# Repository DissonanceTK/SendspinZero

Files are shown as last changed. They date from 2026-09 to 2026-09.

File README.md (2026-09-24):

# Minimalistic Sendspin Media Player for Home Assistant

NOTE: This is a DIY project, those that prefer Off-the-shelf devicea you can buy and use right away, there is a project for that here: https://github.com/RealDeco/sendspin-guition



A tiny [Sendspin](https://www.sendspin-audio.com) media player with **cover art display** and a **weather clock**, built around the **ESP32-S3 Zero**.

This project turns a small, inexpensive ESP32 board into a compact **audio receiver** for your amplifier capable of doing multi-room audio in sync, with a screen for album art, **song**, **artist**, and a weather clock when not playing, OR a Button to control with, or with nothing so you can hide it behind the tv/stereo.

Each version can be built with one of these options:

* Display
* No display
* Big button

That gives a total of **9 variants**:

Variants

---

<div align="center">

## Firmware Installers

<table>
  <tr>
    <th>Device / Configuration</th>
    <th>Installer</th>
  </tr>
  <tr>
    <td><strong>Sendspin Zero Button Analog</strong></td>
    <td></td>
  </tr>
  <tr>
    <td><strong>Sendspin Zero Button Digital</strong></td>
    <td></td>
  </tr>
  <tr>
    <td><strong>Sendspin Zero Display Analog</strong></td>
    <td></td>
  </tr>
  <tr>
    <td><strong>Sendspin Zero Display Digital</strong></td>
    <td></td>
  </tr>
  <tr>
    <td><strong>Sendspin Zero No Display Analog</strong></td>
    <td></td>
  </tr>
  <tr>
    <td><strong>Sendspin Zero No Display Digital</strong></td>
    <td></td>
  </tr>
</table>

<br>

<table>
  <tr>
    <td><strong>Sendspin Zero Control Analog</strong></td>
    <td></td>
  </tr>
  <tr>
    <td><strong>Sendspin Zero Control Digital</strong></td>
    <td></td>
  </tr>
  <tr>
    <td><strong>Sendspin Zero Display + Button Analog</strong></td>
    <td></td>
  </tr>
</table>

<br>

<table>
  <tr>
    <td><strong>SendspinZero Speaker</strong></td>
    <td></td>
  </tr>
  <tr>
    <td><strong>Sendspin Supermini Headphones</strong></td>
    <td></td>
  </tr>
</table>

</div>

---

## About the Project

This started as a fun experiment: I wanted to see if the **ESP32-S3 Zero** would work with Sendspin. Since it has **2 MB of PSRAM**, I figured it *might* be possible—and it turns out, it is.

Once that worked, I thought: instead of building yet another “Sendspin speaker”, why not make a **tiny receiver** for my amplifier?

So I:

* Replaced the **MAX98357** with a **PCM5102A DAC**
* Designed a custom case
* Added a display for **cover art** and a **weather clock**

…and this is the result 🙂

---

## Photos

<p align="center">
  
  
</p>

---

## Cost

All parts were sourced from AliExpress and added up to **just over $10** (last checked).

---

## Parts List

* **1 × ESP32-S3 Zero**
  [https://www.aliexpress.com/item/1005009890203011.html](https://www.aliexpress.com/item/1005009890203011.html)

  (be sure you select esp32-s3, not esp32-c3 which the page defaults to.)

* **1 × PCM5102A DAC**
  [https://www.aliexpress.com/item/1005008130629022.html](https://www.aliexpress.com/item/1005008130629022.html)

* **1 × 1.54" LCD screen**
  [https://www.aliexpress.com/item/1005008703777053.html](https://www.aliexpress.com/item/1005008703777053.html)

---

## Diagram & Pins Used

Wiring diagram

### ⚠️ Assembly Notes

* If you plan to mount everything inside the case, **do NOT solder header pins** to the DAC, ESP32, or display.
  → Solder wires directly to the boards instead, otherwise they won’t fit.

* If your display already has pins:
  → You may need to **bend two pins** slightly to make room for the audio jack.



---

## Pin Mapping

### ESP32-S3 → PCM5102A

| ESP32-S3 GPIO | PCM5102A Pin |
| --- | --- |
| GPIO4 | LRCK |
| GPIO5 | BCK |
| GPIO6 | DIN |

### ESP32-S3 → Display

| ESP32-S3 GPIO | Display Pin |
| --- | --- |
| GPIO7 | SCL |
| GPIO8 | SDA |
| GPIO9 | RST |
| GPIO10 | DC |
| GPIO11 | BL |

### Power (both modules)

* **GND**
* **3.3V**

# >>>> Important DAC Setup <<<< (or there will be no sound)

Make sure to:

* Solder the 4 control pads on the **back of the PCM5102A** (also shown below):
  * H1L -> L
  * H2L -> L
  * H3L -> H
  * H4L -> L
* Solder the bridge near **SCK on the front** (some boards come pre-soldered)



---

## Toslink (Optical Audio) Version

This version has **no display** and is the easiest build—**under $10** 🙂

(For display or button versions, pin usage is the same)

Toslink version

Your soundbar will love you for it 😉
3D files are in [`3D_Files`](3D_Files)

### Pin Mapping

### ESP32-S3 → Toslink Connector

| ESP32-S3 GPIO | TOSLINK |
| --- | --- |
| GPIO4 | VIN (DATA) |
| 3.3V | VCC |
| GND | GND |

Pins

### Parts

* Single: [https://www.aliexpress.com/item/1005011593001325.html](https://www.aliexpress.com/item/1005011593001325.html)
* 1–10 pcs: [https://www.aliexpress.com/item/1005008393864163.html](https://www.aliexpress.com/item/1005008393864163.html)
* Cables: [https://www.aliexpress.com/item/1005008202856228.html](https://www.aliexpress.com/item/1005008202856228.html)

- 1 × M2.6×10 self-tapping screw

⚠️ **Important:** Select **"Transmitting end" (A1)**

---

## Coax (Digital Audio) Version

Simplest version of all: **just two wires and a resistor**.

Coax version

3D files are in [`3D_Files`](3D_Files)

### Pin Mapping

### ESP32-S3 → RCA Connector

| ESP32-S3 GPIO | RCA |
| --- | --- |
| GPIO4 | VIN (DATA) |
| GND | GND |

### Parts

* 1 pcs. 332-470ohm resistor [https://www.aliexpress.com/item/1005005252979796.html](https://www.aliexpress.com/item/1005005252979796.html)

* RCA female: [https://www.aliexpress.com/item/1005010424983352.html](https://www.aliexpress.com/item/1005010424983352.html)
* Cables: [https://www.aliexpress.com/item/1005008202856228.html](https://www.aliexpress.com/item/1005008202856228.html)

---

## Button Version

Instead of a display, you can use a **large illuminated button**.

### Controls

* **Single click** → Play / pause
* **Double click** → Next track
* **Triple click** → Previous track
* **Hold** → Toggle Sendspin / Home Assistant control mode

In HA mode, clicks are exposed for automations.



3D files are in [`3D_Files`](3D_Files)

### Pin Mapping

| ESP32-S3 GPIO | Button |
| --- | --- |
| GPIO1 | 1 |
| GPIO2 | 3 |
| GPIO3 | 4 |
| GND | 2 + 5  |



### Part

**22mm Bicolor (RG) Black 3–6V**
[https://www.aliexpress.com/item/1005004920346156.html](https://www.aliexpress.com/item/1005004920346156.html)

---

## SendspinZero-Control (Knob + Button + Display)

This version uses a combo board with a **rotary encoder + button + display i found cheap on aliexpress**.



3D files are in [`3D_Files`](3D_Files)

### Additional Pins

(Same as display version + these)

| ESP32-S3 GPIO | Combo Board |
| --- | --- |
| GPIO12 | TRA |
| GPIO13 | TRB |
| GPIO43 (TX) | PSH |
| GPIO44 (RX) | KO |

(TX = GPIO43, RX=GPIO44 on the zero board)



### Part

ESP32-S3 Zero and PCM5102A as above +

[https://www.aliexpress.com/item/1005009900611104.html](https://www.aliexpress.com/item/1005009900611104.html)

---

## Display + Button Version



3D files are in [`3D_Files`](3D_Files)

### Pin Mapping

Same as SendspinZero-Display + SendspinZero-Button

### Parts

same components as the other versions (esp32-s3 + PCM5102A DAC + Button) +

* 1.9" screen: [https://www.aliexpress.com/item/1005007098895718.html](https://www.aliexpress.com/item/1005007098895718.html)

---

## Speaker amplifier version





NO 3D files made for this device.

This is the only device with amplifier onboard, it's mono so for stereo speakers you need a module for each speaker and have them playing as stereo in MA.

### Pin Mapping
(remove two pins from the spacer and solder the boards together)

| ESP32-S3 GPIO | MAX98357 |
| --- | --- |
| VCC (5V) | Vin |
| GND | GND |
| *not used* | SD |
| *not used* | GAIN |
| GPIO2 | DIN |
| GPIO3 | BCLK |
| GPIO4 | LRC |

GAIN pin can be connected to GND for 12db gain. (or with 100k resistor to GND for 15db gain)

### Parts

same esp32-s3 zero as the other versions +

* MAX98357: https://www.aliexpress.com/item/1005007003802663.html

---

## Supermini Headphone amplifier version (make corded headphones wireless)



3D files are in [`3D_Files`](3D_Files)

This is the only device based on esp32-s2 Supermini due to it's battery connection.

### Pin Mapping

| ESP32-S3 GPIO | DAC |
| --- | --- |
| VCC (3V) | VCC |
| GND | GND |
| GPIO6 | DIN |
| GPIO7 | BCK |
| GPIO5 | WS |

| ESP32-S3 GPIO | Touch board |
| --- | --- |
| VCC (3V) | VCC |
| GND | GND |
| GPIO4 | I/O |

| ESP32-S3 GPIO | battery |
| --- | --- |
| + pole on back| + |
| - pole on back| - |

## Parts List

* **1 × ESP32-S3 Supermini** https://www.aliexpress.com/item/1005010376539004.html

* **1 × Headphone amplifier DAC** https://www.aliexpress.com/item/1005008889469187.html

* **1 × Touch sensor** https://www.aliexpress.com/item/4000540638639.html

* **1 × 3.7V 802035-500Mah Battery** (bought mine on temu but can be found on aliexpress too)

* **1 x 4mm switch** https://www.aliexpress.com/item/1005010432259017.html

(3D file includes both with and without hole for switch)

---

## SendspinZero-Source

This device differs from the others by being an input device instead of an output device.

When the Sendspin Source role is supported in ESPHome, it will allow external audio devices such as turntables, radios, cassette decks, CD players, and other devices with audio output to be connected to Music Assistant and played in sync across your Sendspin devices.







Important to remove two capasitors from the PCM1808 or the sound would not be clear:

[Open video](https://github.com/user-attachments/assets/831a7ad7-ee62-4282-af22-7b3cd60827db)

3D files are in [`3D_Files`](3D_Files)

## Pin Mapping

### ESP32-S3 → PCM1808

| ESP32S3 Zero  | PCM1808 pin	|
| --- | ---|
| 5V		| 5V		|
| GND		| GND		|
| 3.3V		| 3.3V		|
| GPIO 3	| BCK		|
| GPIO 4	| OUT		|
| GPIO 5	| LRC		|
| GPIO 6	| SCK		|

| 3.5mm jack	| PCM1808 pin	|
| --- | ---|
| Right		| RIN		|
| GND		| - (GND)	|
| Left		| LIN		|

## Parts List

* **1 × ESP32-S3 Zero**
  [https://www.aliexpress.com/item/1005009890203011.html](https://www.aliexpress.com/item/1005009890203011.html)

  (be sure you select esp32-s3, not esp32-c3 which the page defaults to.)

* **1 × PCM1808 ADC**
  [https://www.aliexpress.com/item/1005008885079639.html](https://www.aliexpress.com/item/1005008885079639.html)

* **1 × 3.5mm female Jack**
  [https://www.aliexpress.com/item/1005008243857446.html](https://www.aliexpress.com/item/1005008243857446.html)

* 10 short cords.

---

EOL

---

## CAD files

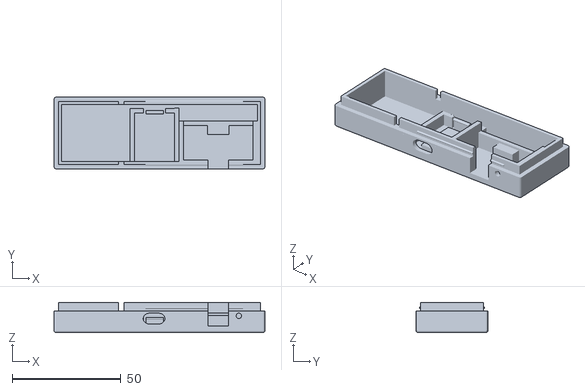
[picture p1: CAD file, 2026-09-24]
3D_Files/SendspinZero-Display_Button-Toslink-bottom.stl
97.0 x 33.0 x 14.0

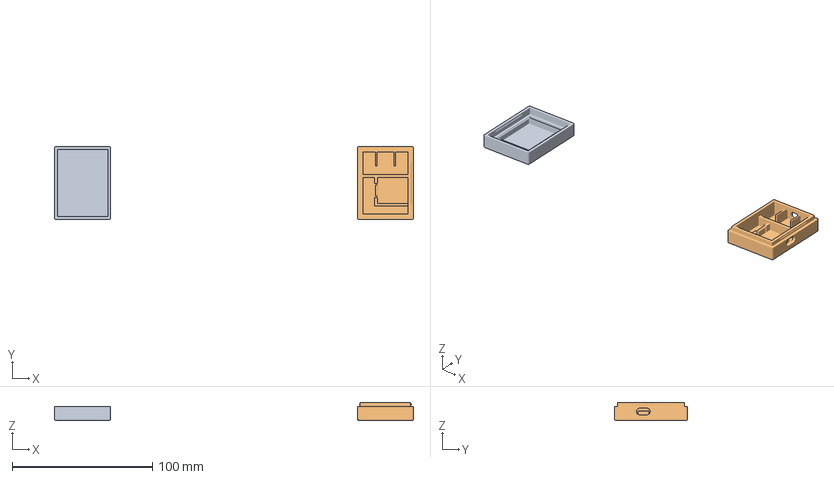
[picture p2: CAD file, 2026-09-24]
3D_Files/sendspinzero_source.3mf
256.0 x 52.0 x 13.0 mm
sendspinzero_source-top.stl
sendspinzero_source-bottom.stl

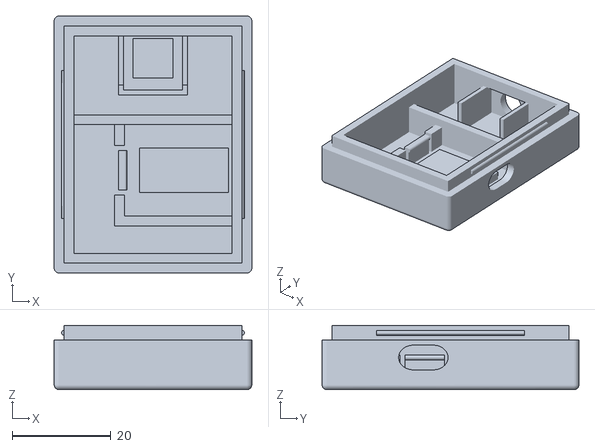
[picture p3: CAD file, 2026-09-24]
3D_Files/sendspinzero_source-bottom.stl
40.0 x 52.0 x 13.0

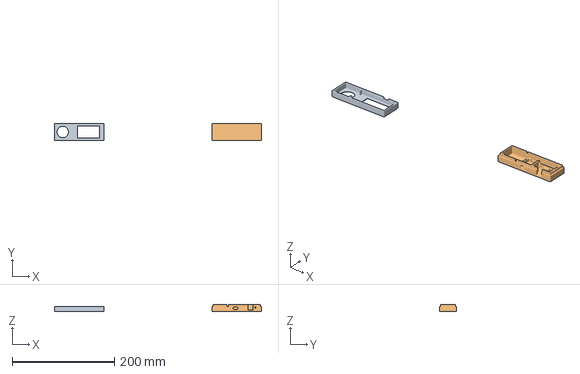
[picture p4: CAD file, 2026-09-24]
3D_Files/SendspinZero-Display_Button-Toslink.3mf
404.2 x 33.0 x 14.0 mm
1.9toslink-top.stl
1.9toslink-bottom.stl

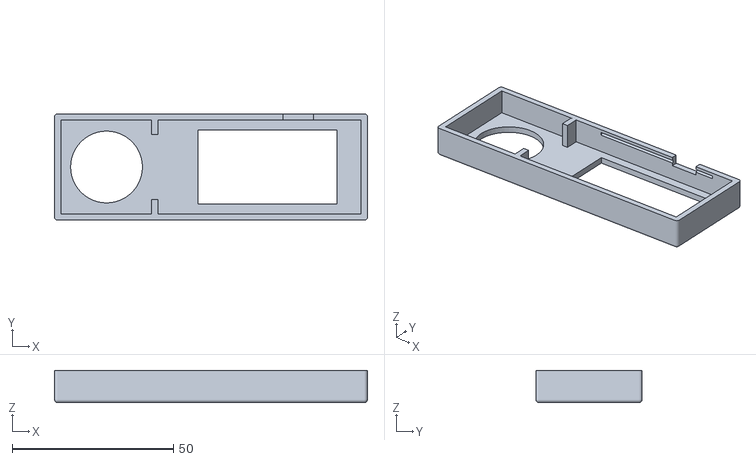
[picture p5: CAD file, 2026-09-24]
3D_Files/SendspinZero-Display_Button-Toslink-top.stl
97.0 x 33.0 x 10.0

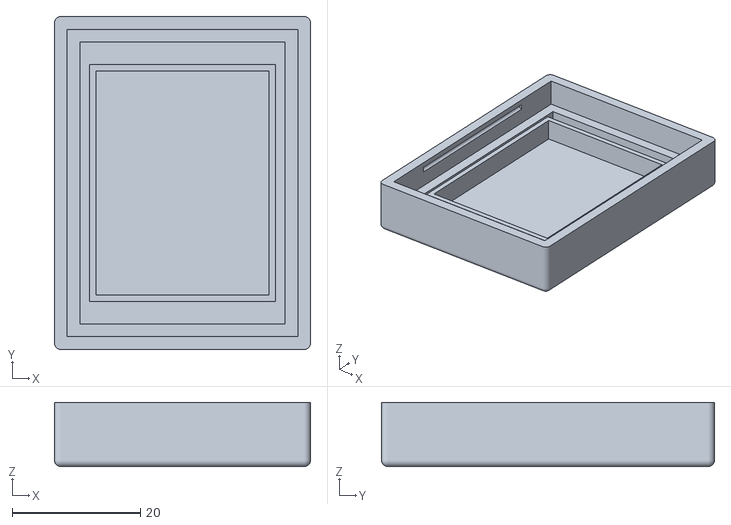
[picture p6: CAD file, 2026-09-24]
3D_Files/sendspinzero_source-top.stl
40.0 x 52.0 x 10.0

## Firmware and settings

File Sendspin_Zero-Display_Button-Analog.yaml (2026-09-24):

substitutions:
  name: zero-display-button
  friendly_name: Zero Display Button

  ha_weather_entity: weather.forecast_home

  ## Startup sound, options are: Home_Connected or Home_Connected_Male
  startup_sound_file: Home_Connected # Home_Connected, popup, available, Server_Connected

  # Image model options are: AlbertQuackmore, Alita, Casita, Gwen, HA-character, ha-girl, Hacker, Salem, Sarah, Shaun
  imagemodel: "ha-girl"

  media_sample_rate: 48000

packages:
  extcomp:
    url: https://github.com/DissonanceTK/xiaozhi-esphome.git
    ref: main
    refresh: 0s
    files:
      - devices/Under_Development/Modular/HW/sendspin-external_components_2026.8.0.yaml


esphome:
  name: ${name}
  friendly_name: ${friendly_name}
  min_version: 2026.9.0
  name_add_mac_suffix: true
  project:
    name: realdeco.sendspin_zero
    version: "2026.9.0"
  on_boot:
    priority: -100
    then:
      - script.execute: update_status_leds
      - script.execute: update_weather_display
      - lvgl.page.show: idle_page

esp32:
  variant: esp32s3
  flash_size: 4MB
  framework:
    type: esp-idf

logger:
  level: WARN

api:
  on_client_connected:
    - lambda: |-
        if (!id(boot_sound_played)) {
          id(boot_sound_played) = true;
          if (id(startup_sound_switch).state) {
            id(play_sound)->execute(true, std::string("ready_sound"));
          }
        }
    - delay: 5s
    - script.execute: update_weather_display
    - script.execute: fetch_daily_forecast

ota:
  - platform: esphome

wifi:
  ap:

improv_serial:

psram:
  mode: quad
  speed: 80MHz

captive_portal:

time:
  - platform: homeassistant
    id: homeassistant_time

globals:
  - id: sendspin_album_art_valid
    type: bool
    restore_value: no
    initial_value: "false"
  - id: last_album_art_valid
    type: bool
    restore_value: false
    initial_value: 'false'
  - id: media_menu_active
    type: bool
    restore_value: no
    initial_value: "false"
  - id: media_menu_index
    type: int
    restore_value: no
    initial_value: "0"
  - id: selected_media_name
    type: std::string
    restore_value: no
    initial_value: '""'
  - id: selected_media_url
    type: std::string
    restore_value: no
    initial_value: '""'
  - id: menu_button_hold_fired
    type: bool
    restore_value: no
    initial_value: "false"
  - id: menu_button_wait_for_release
    type: bool
    restore_value: no
    initial_value: "false"
  - id: boot_sound_played
    type: bool
    restore_value: no
    initial_value: "false"

image:
  - platform: file
    file: https://raw.githubusercontent.com/RealDeco/xiaozhi-esphome/main/images/${imagemodel}/240x240/playing.png
    id: fallback_playing_image
    resize: 170x170
    type: RGB565
    dither: NONE

  - platform: sendspin
    id: album_slot
    format: JPEG
    type: RGB565
    resize: 170x170
    display_offset: 1s
    current_image:
      id: album_art
    transition_image:
      id: album_art_transition
    on_image_display:
      - lambda: |-
          id(sendspin_album_art_valid) = true;
      - if:
          condition:
            lambda: 'return id(last_album_art_valid);'
          then:
            - lvgl.image.update:
                id: outgoing_art
                src: album_art_transition
          else:
            - lvgl.image.update:
                id: outgoing_art
                src: fallback_playing_image
      - lvgl.image.update:
          id: incoming_art
          src: album_art
      - lvgl.animation.start: album_art_crossfade
    on_image_clear:
      - logger.log:
          format: "Album art cleared"
          level: WARN
      - lambda: |-
          id(sendspin_album_art_valid) = false;
      - lvgl.image.update:
          id: incoming_art
          src: fallback_playing_image
      - lvgl.animation.start: album_art_crossfade
    on_image_error:
      - logger.log:
          format: "Album art error"
          level: WARN
      - lambda: |-
          id(sendspin_album_art_valid) = false;

sendspin:
  id: sendspin_hub

i2s_audio:
  - id: i2s_audio_bus
    i2s_lrclk_pin: GPIO4
    i2s_bclk_pin: GPIO5

speaker:
  - platform: i2s_audio
    id: box_speaker
    i2s_audio_id: i2s_audio_bus
    i2s_dout_pin: GPIO6
    dac_type: external
    channel: stereo

  - platform: mixer
    id: mixing_speaker
    output_speaker: box_speaker
    num_channels: 2
    source_speakers:
      - id: announcement_mixing_input
      - id: media_mixing_input

  - platform: resampler
    id: announcement_resampling_speaker
    output_speaker: announcement_mixing_input
    sample_rate: ${media_sample_rate}
    bits_per_sample: 16

  - platform: resampler
    id: media_resampling_speaker
    output_speaker: media_mixing_input
    sample_rate: ${media_sample_rate}
    bits_per_sample: 16

audio_file:
  - id: ready_sound
    file: https://github.com/RealDeco/xiaozhi-esphome/raw/main/sounds/${startup_sound_file}.flac
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

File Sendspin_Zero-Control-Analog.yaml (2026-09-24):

substitutions:
  name: zero-control
  friendly_name: Sendspin Zero Control

## SETTINGS ######################################################################################################################################

  ## Startup sound, options are: Home_Connected or Home_Connected_Male
  startup_sound_file: popup # Home_Connected, popup, available, Server_Connected

  ## Sample rate for DAC
  media_sample_rate: 48000

## ROTATION: THIS PART IS ONLY NEEDED IF YOU TURNED DISPLAY AROUND IN CASE #######################################################################

  ## 0 degree (default)
  display_swap_xy: "false"
  display_mirror_x: "false"
  display_mirror_y: "false"
  display_offset_width: "0"
  display_offset_height: "0"

  ## 180 degree
  # display_swap_xy: "false"
  # display_mirror_x: "true"
  # display_mirror_y: "true"
  # display_offset_width: "0"
  # display_offset_height: "80"

## SENDSPIN SETTINGS #############################################################################################################################

packages:
  extcomp:
    url: https://github.com/RealDeco/xiaozhi-esphome.git
    ref: main
    refresh: 0s
    files:
      - devices/Under_Development/Modular/HW/sendspin-external_components_2026.8.0.yaml

#packages: # local
#  extcomp: !include localtest/HW/sendspin-external_components_2026.8.0.yaml
        
## END OF SETTINGS ###############################################################################################################################

esphome:
  name: ${name}
  friendly_name: ${friendly_name}
  min_version: 2026.9.0
  name_add_mac_suffix: true
  project:
    name: realdeco.sendspin_zero
    version: "2026.9.0"
  on_boot:
    priority: -100
    then:
      - lvgl.page.show: idle_page

esp32:
  variant: esp32s3
  flash_size: 4MB
  framework:
    type: esp-idf

logger:
  level: WARN

api:
  on_client_connected:
    - lambda: |-
        if (!id(boot_sound_played)) {
          id(boot_sound_played) = true;
          if (id(startup_sound_switch).state) {
            id(play_sound)->execute(true, std::string("ready_sound"));
          }
        }
    - delay: 5s
    - script.execute: fetch_daily_forecast

ota:
  - platform: esphome

wifi:
  ap:

improv_serial:

psram:
  mode: quad
  speed: 80MHz

captive_portal:

time:
  - platform: homeassistant
    id: homeassistant_time

globals:
  - id: sendspin_album_art_valid
    type: bool
    restore_value: no
    initial_value: "false"

  - id: last_album_art_valid
    type: bool
    restore_value: false
    initial_value: 'false'

  - id: boot_sound_played
    type: bool
    restore_value: no
    initial_value: "false"

  - id: knob_popup_active
    type: bool
    restore_value: no
    initial_value: "false"

  - id: knob_control_pct
    type: int
    restore_value: no
    initial_value: "0"

  - id: volume_control_pct
    type: int
    restore_value: no
    initial_value: "0"

  - id: popup_mode_light
    type: bool
    restore_value: no
    initial_value: "false"


  - id: control_menu_active
    type: bool
    restore_value: no
    initial_value: "false"

  - id: selected_control_index
    type: int
    restore_value: yes
    initial_value: "1"

  - id: volume_control_target_group
    type: bool
    restore_value: yes
    initial_value: "false"

  - id: control_menu_cursor
    type: int
    restore_value: no
    initial_value: "1"

  - id: control_menu_turn_halfstep
    type: bool
    restore_value: no
    initial_value: "false"

  - id: media_menu_active
    type: bool
    restore_value: no
    initial_value: "false"

  - id: media_menu_cursor
    type: int
    restore_value: no
    initial_value: "1"

  - id: media_menu_turn_halfstep
    type: bool
    restore_value: no
    initial_value: "false"

  - id: group_play_active
    type: bool
    restore_value: no
    initial_value: "false"

  - id: media_button_click_count
    type: int
    restore_value: no
    initial_value: "0"

  - id: media_button_hold_fired
    type: bool
    restore_value: no
    initial_value: "false"
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

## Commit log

2026-08-02 Refactor Sendspin configuration and update parameters
    Updated media sample rate, image file URLs, and component IDs. Adjusted minimum version and added new logging for album art display.
2026-08-02 Refactor Sendspin configuration and update parameters
    Updated media sample rate, version numbers, and file references. Adjusted delays and album art handling in the configuration.
2026-08-02 Update YAML configuration for Sendspin device
2026-08-08 Refactor LED scripts and add album art animations
    Removed LED control scripts and added album art transition animations.
2026-08-08 Refactor album art handling and remove LED scripts
2026-08-08 Update version and add song title, artist, and album sensors
    Updated minimum version and added text sensors for song details.
2026-08-08 Update YAML configuration for Sendspin device
    Updated minimum version and added new button and text sensor configurations.
2026-08-08 Add button and text sensors for song information
    Added buttons and text sensors for song details and restart action.
2026-08-08 Update version and add song info sensors
    Updated minimum version and added new button and text sensors for song information.
2026-08-08 Update version and add restart button and text sensors
    Updated minimum version and added new button and text sensors for song details.
2026-08-08 Update minimum version and add new button configuration
2026-08-09 Update for RG+ button
2026-09-19 Update README with note on off-the-shelf devices
    Added a note about off-the-shelf Sendspin devices.
2026-09-19 Update README with pin mapping details
    Added pin mapping information for ESP32-S3 and PCM1808.
2026-09-22 Enhance README with SendspinZero-Source details and parts list
    Added details about the SendspinZero-Source device, including its functionality and parts list. Updated images and removed placeholder text.
